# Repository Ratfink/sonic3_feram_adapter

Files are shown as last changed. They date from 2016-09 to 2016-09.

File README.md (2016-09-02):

# sonic3_feram_adapter
Breakout/adapter board for replacing the FeRAM chip in a Sonic 3 cartridge with
a modern chip.

## Licensing
Copyright © 2016 Clayton G. Hobbs.

This work is licensed under the Creative Commons Attribution-ShareAlike 4.0
International License. To view a copy of this license, visit
http://creativecommons.org/licenses/by-sa/4.0/ or send a letter to Creative
Commons, PO Box 1866, Mountain View, CA 94042, USA.

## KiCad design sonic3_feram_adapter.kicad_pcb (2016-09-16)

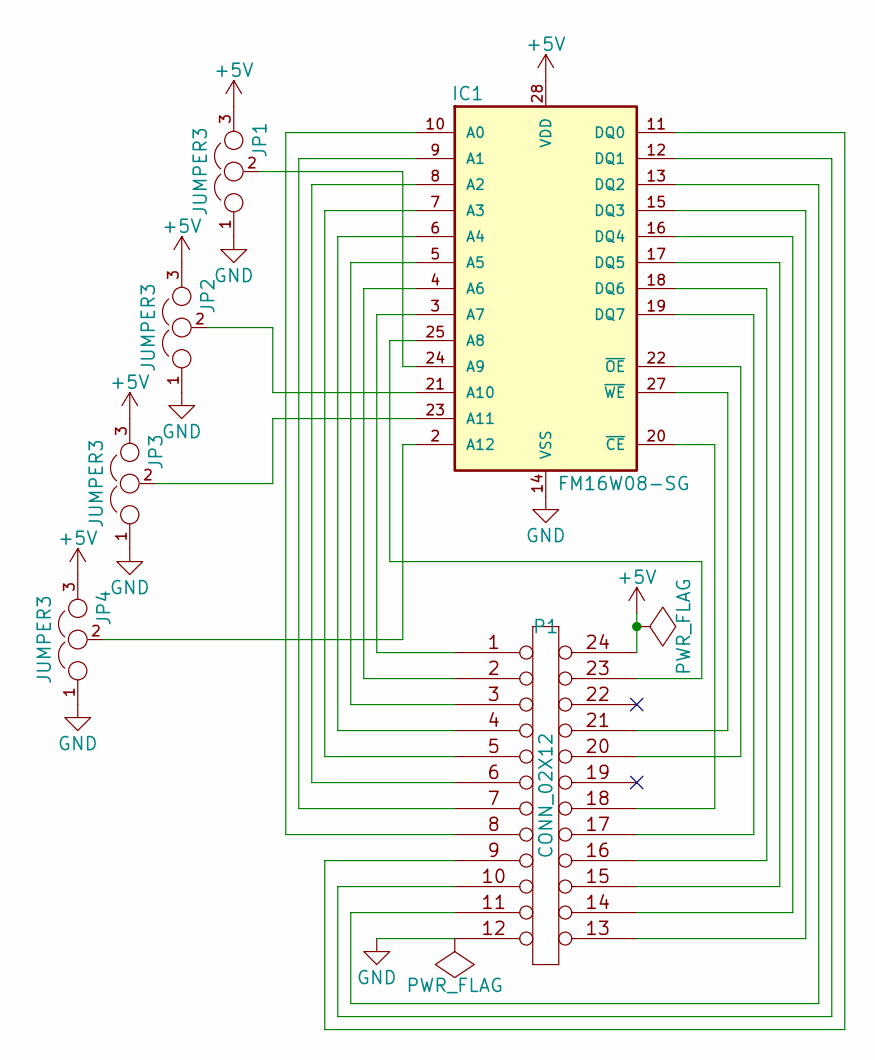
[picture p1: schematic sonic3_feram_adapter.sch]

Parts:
IC1: FM16W08-SG; SOIC-28_7.5x17.9mm_Pitch1.27mm
JP1, JP2, JP3, JP4: JUMPER3; SOLDER-JUMPER_2-WAY
P1: CONN_02X12; DIP-24_W15.24mm

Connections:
+5V: IC1.28 (VDD), JP1.3, JP2.3, JP3.3, JP4.3, P1.24
GND: IC1.14 (VSS), JP1.1, JP2.1, JP3.1, JP4.1, P1.12
unnamed: IC1.2 (A12), JP4.2
unnamed: IC1.3 (A7), P1.1
unnamed: IC1.4 (A6), P1.2
unnamed: IC1.5 (A5), P1.3
unnamed: IC1.6 (A4), P1.4
unnamed: IC1.7 (A3), P1.5
unnamed: IC1.8 (A2), P1.6
unnamed: IC1.9 (A1), P1.7
unnamed: IC1.10 (A0), P1.8
unnamed: IC1.11 (DQ0), P1.9
unnamed: IC1.12 (DQ1), P1.10
unnamed: IC1.13 (DQ2), P1.11
unnamed: IC1.15 (DQ3), P1.13
unnamed: IC1.16 (DQ4), P1.14
unnamed: IC1.17 (DQ5), P1.15
unnamed: IC1.18 (DQ6), P1.16
unnamed: IC1.19 (DQ7), P1.17
unnamed: IC1.20 (~CE~), P1.18
unnamed: IC1.21 (A10), JP2.2
unnamed: IC1.22 (~OE~), P1.20
unnamed: IC1.23 (A11), JP3.2
unnamed: IC1.24 (A9), JP1.2
unnamed: IC1.25 (A8), P1.23
unnamed: IC1.27 (~WE~), P1.21

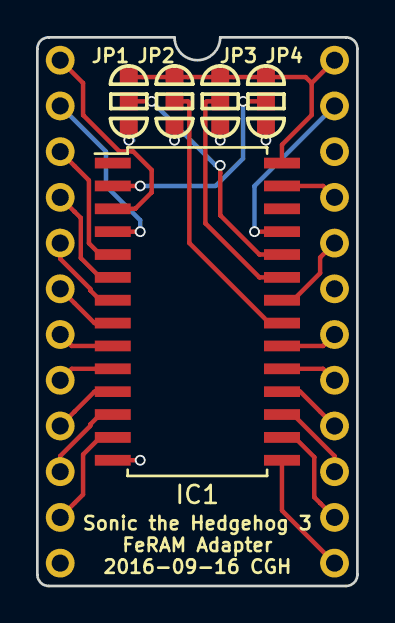
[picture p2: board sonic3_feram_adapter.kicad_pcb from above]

Board: 2 copper layers, 17.8 x 30.5 mm, 6 parts (0 on the bottom side), 26 nets.

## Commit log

2016-09-02 Initial commit
    Added all the KiCAD files of the complete board, as well as a README and
    gitignore.
    [sonic3_feram_adapter.kicad_pcb, sonic3_feram_adapter.sch]
2016-09-02 Corrected PCB back text
    SMS is not Genesis, SMD is Genesis.
    [sonic3_feram_adapter.kicad_pcb]
2016-09-16 Added jumpers for bank selection
    Since this board adapts an 8 KiB chip to work in the place of a 512 B
    chip, it seems like it would be nice to allow the user to change which
    block of 512 B is in use. To allow this, I added solder bump jumpers to
    the high address lines so they can be pulled to ground or 5 V.
    [sonic3_feram_adapter.kicad_pcb, sonic3_feram_adapter.sch]
2016-09-16 Improved footprint for header pins
    No more outline for an IC, and the designator is on the bottom of the
    board.
    [sonic3_feram_adapter.kicad_pcb]
2016-09-16 Updated date on silkscreen
    [sonic3_feram_adapter.kicad_pcb]
